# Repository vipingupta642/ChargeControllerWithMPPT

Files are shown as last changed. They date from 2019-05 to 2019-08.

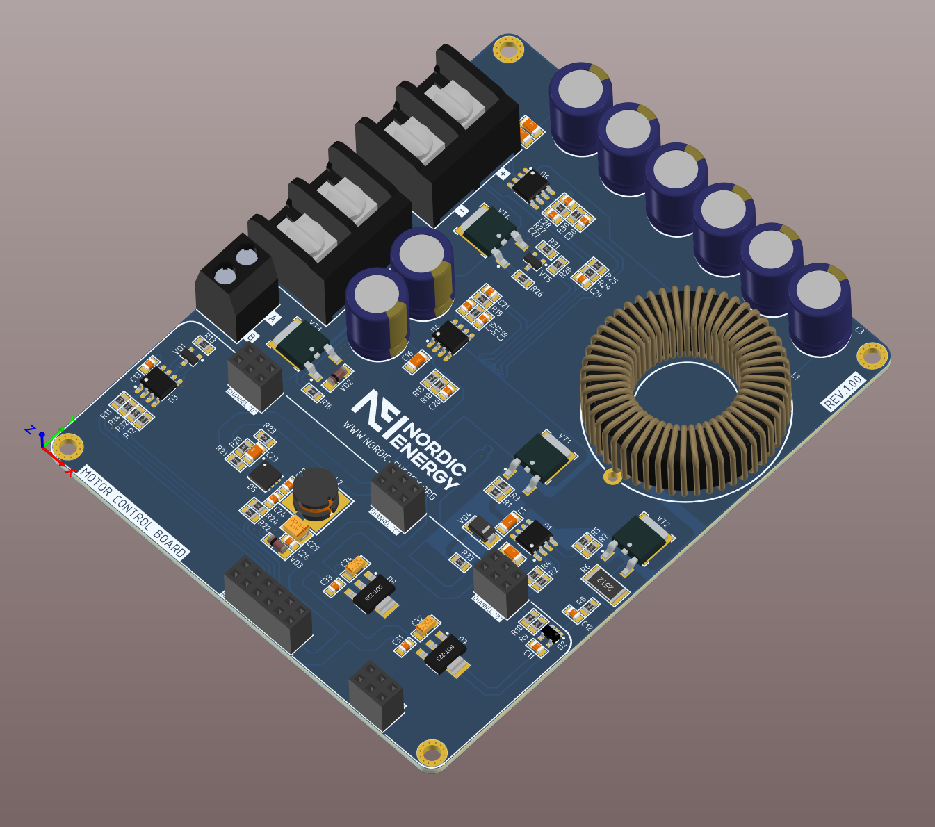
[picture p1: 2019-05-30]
Hardware/Mechanical/3D view. Part 1.PNG

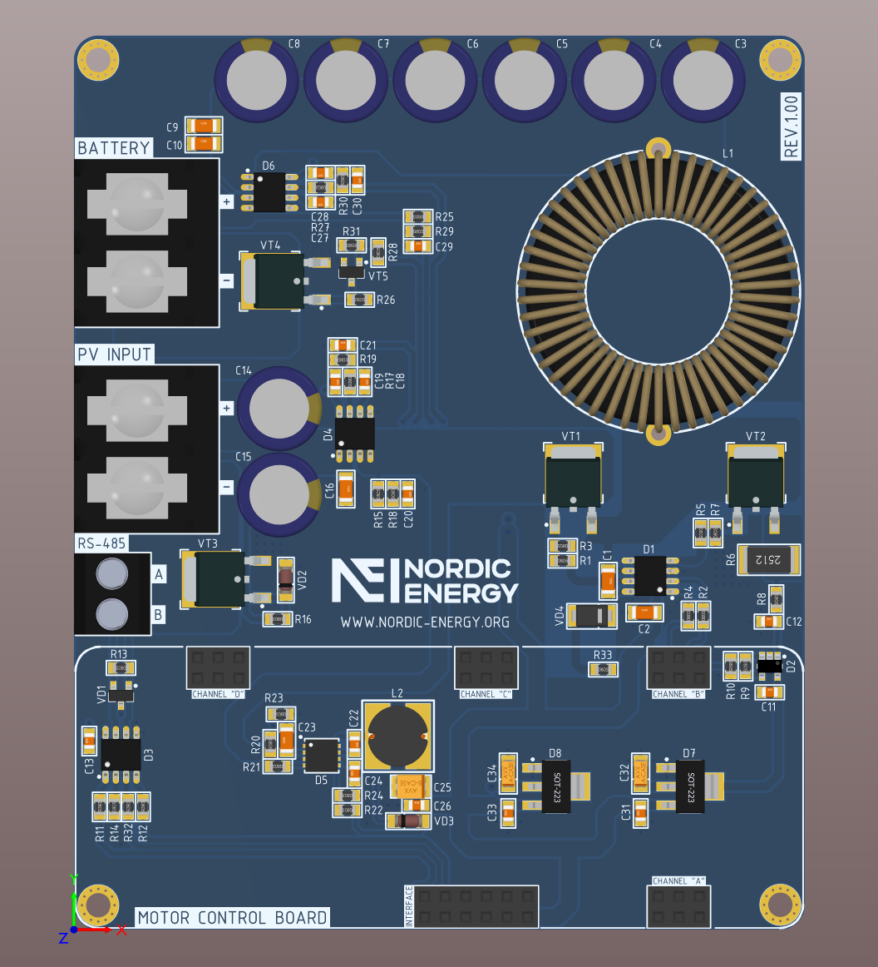
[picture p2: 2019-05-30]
Hardware/Mechanical/3D view. Part 2.PNG

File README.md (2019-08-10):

# МРРТ контроллер заряда батареи

Контроллер заряда создан на базе модуля [*MotorControlBoard*](https://github.com/Nordic-Energy/MotorControlBoard) и управляется с помощью специализированного микроконтроллера STM32F334C8T6 с высокоразрядным ШИМ-контроллером (HRPWM) на борту. Применение данного устройства возможно, как в роли отладочного комплекса для изучения алгоритмов поиска точки максимальной мощности (ТММ), так в качестве законченного устройства для работы в автономной солнечной электростанции мощностью до 500 Вт.

Фото МРРТ

При разработке контроллера заряда основной упор делается на создание надежной аппаратной части с применением лучших компонентов и на реализацию максимальной эффективных алгоритмов поиска ТММ. В контроллере отсутствую электролитические конденсаторы, вместо них примененые твердотельные полимерные конденсаторы с повышенным сроком службы, что позволит обеспечить устройству гарантированный ресурс работы 10 лет. Это приведет к увеличению надежности автономных мини-электростанций и снижению затрат на обслуживание оборудования.

# Технические характеристики

* Входное напряжение: *15...60В*
* Выходное напряжение: *12/24В*
* Выходной зарядный ток: *20А*
* Стабилизация тока: *±1,5%*
* Стабилизация напряжения: *±2%*
* Рабочая частота: *100кГц*
* КПД, не менее: *94%*
* Алгоритмы МРРТ: *да*
* Интерфейсы: *USB, RS485*
* Габаритные размеры: *110х90х20мм*
* Температура эксплуатации: *-20...+65<sup>o</sup>C*

# Структура проекта

* Firmware
    * Documents
    * ChargeControllerWithMPPT

>

* Hardware
    * Documents
    * Manufacture
    * AltiumProject
    * Mechanical

# Печатная плата

Контроллер заряда состоит из двух плат: [*MotorControlBoard*](https://github.com/Nordic-Energy/MotorControlBoard) и основная силовая  двухслойная плата, которая изготавливается на стеклотекстолите FR-4 толщиной не менее 1 мм (рекомендовано 1,6 мм) и имеет размеры 110х90 мм.

Печатная плата МРРТ контроллера

# Используемые инструменты

* [Altium Designer](https://www.altium.com/altium-designer/ "Официальный сайт CAD")
* [Visual Studio Code](https://code.visualstudio.com/ "Официальный сайт IDE")
* [GNU Arm Embedded Toolchain](https://github.com/gnu-mcu-eclipse/arm-none-eabi-gcc/releases/tag/v8.2.1-1.4 "Официальный сайт плагина")
* [JLink](https://www.segger.com/downloads/jlink/#J-LinkSoftwareAndDocumentationPack "Официальный сайт")

# Лицензирование

Все исходные материалы для проекта распространяются по лицензии [MIT](./LICENSE "Описание лицензии"). Вы можете использовать проект в любом виде, в том числе и для коммерческой деятельности, но стоит помнить, что автор проекта не дает никаких гарантий на работоспособность устройства или частей проекта, а так же не несет никакой ответственности по искам или за нанесенный ущерб.

# Контакты

* E-mail: *ilya@nordic-energy.org*
* Telegram: [*@aiki01*](https://t.me/aiki01 "Чат в телеграмме")

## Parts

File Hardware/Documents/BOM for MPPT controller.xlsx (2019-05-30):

Value | Designator | Manufacturer | Model | Quantity
0.47μF | C1 | Yageo | CC1206KRX7R8BB474 | 1
2.2μF | C2, C9, C10 | Yageo | CC1206KKX7R9BB225 | 3
330μF | C3, C4, C5, C6, C7, C8 | Panasonic | 35SEK330M | 6
0.1μF | C11, C13, C19, C20, C21, C28, C29, C30 | Yageo | CC0805KRX7R8BB104 | 8
1nF | C12, C18, C27 | Yageo | CC0805KRX7R9BB102 | 3
100μF | C14, C15 | Wurth | 860010775014 | 2
1μF | C16, C23 | Samsung | CL31B105KCHSNNE | 2
0.01μF | C22 | Yageo | CC0805KRX7R9BB103 | 1
2.2μF | C24 | Yageo | CC0805KKX7R6BB225 | 1
10μF | C25 | AVX | TAJB106K025RNJ | 1
2.2μF | C26 | Yageo | CC0805KKX7R7BB225 | 1
1μF | C31, C33 | Yageo | CC0805JKX7R7BB105 | 2
100μF | C32, C34 | AVX | TLJA107M006R0800 | 2
 | D1 | ON Semiconductor | NCP5183DR2G | 1
 | D2 | Texas Instruments | LMV321IDBVR | 1
 | D3 | Texas Instruments | SN65HVD3082EDR | 1
 | D4, D6 | Allegro MicroSystems | ACS713ELCTR-30A-T | 2
 | D5 | Texas Instruments | LM5017SD/NOPB | 1
 | D7 | Diodes Incorporated | AZ1117IH-3.3TRG1 | 1
 | D8 | Diodes Incorporated | AZ1117IH-5.0TRG1 | 1
30μH | L1 | Magnetics | 0077071A7 | 1
220μH | L2 | Bourns | SDR0805-221KL | 1
2R4 | R1, R5, R33 | Yageo | RC0805JR-072R4L | 3
100R | R2, R4, R8, R11, R12, R28, R32 | Yageo | RC0805JR-07100RL | 7
10k | R3, R7, R14, R16, R26, R31 | Yageo | RC0805JR-0710KL | 6
0R004 | R6 | Yageo | PA2512FKF7W0R004E | 1
30k | R9 | Yageo | RC0805FR-0730KL | 1
1k | R10 | Yageo | RC0805FR-071KL | 1
120R | R13 | Yageo | RC0805FR-07120RL | 1
100k | R15 | Yageo | RC0805FR-07100KL | 1
5k6 | R17, R18, R27 | Yageo | RC0805FR-075K6L | 3
10k | R19, R23, R24, R29, R30 | Yageo | RC0805FR-0710KL | 5
91k | R20 | Yageo | RC0805FR-0791KL | 1
499k | R21 | Yageo | RC0805FR-07499KL | 1
88k7 | R22 | Yageo | RC0805FR-0788K7L | 1
82k | R25 | Yageo | RC0805FR-0782KL | 1
 | VD1 | ON Semiconductor | SZNUP2105LT1G | 1
16V | VD2 | Central Semiconductor | CLL5246B TR | 1
 | VD3 | ON Semiconductor | LL4148 | 1
 | VD4 | SMC Diode | SS210ATR | 1
 | VT1, VT2, VT3, VT4 | Infineon | IPD053N08N3GATMA1 | 4
 | VT5 | ON Semiconductor | BC847ALT1G | 1
 | X1 | Connfly | PBD-12 | 1
 | X2, X3, X4, X5 | Connfly | PBD-6 | 4
 | X6 | Molex | 0395430002 | 1
 | X7, X8 | TE Connectivity | 6PCV-02-006 | 2

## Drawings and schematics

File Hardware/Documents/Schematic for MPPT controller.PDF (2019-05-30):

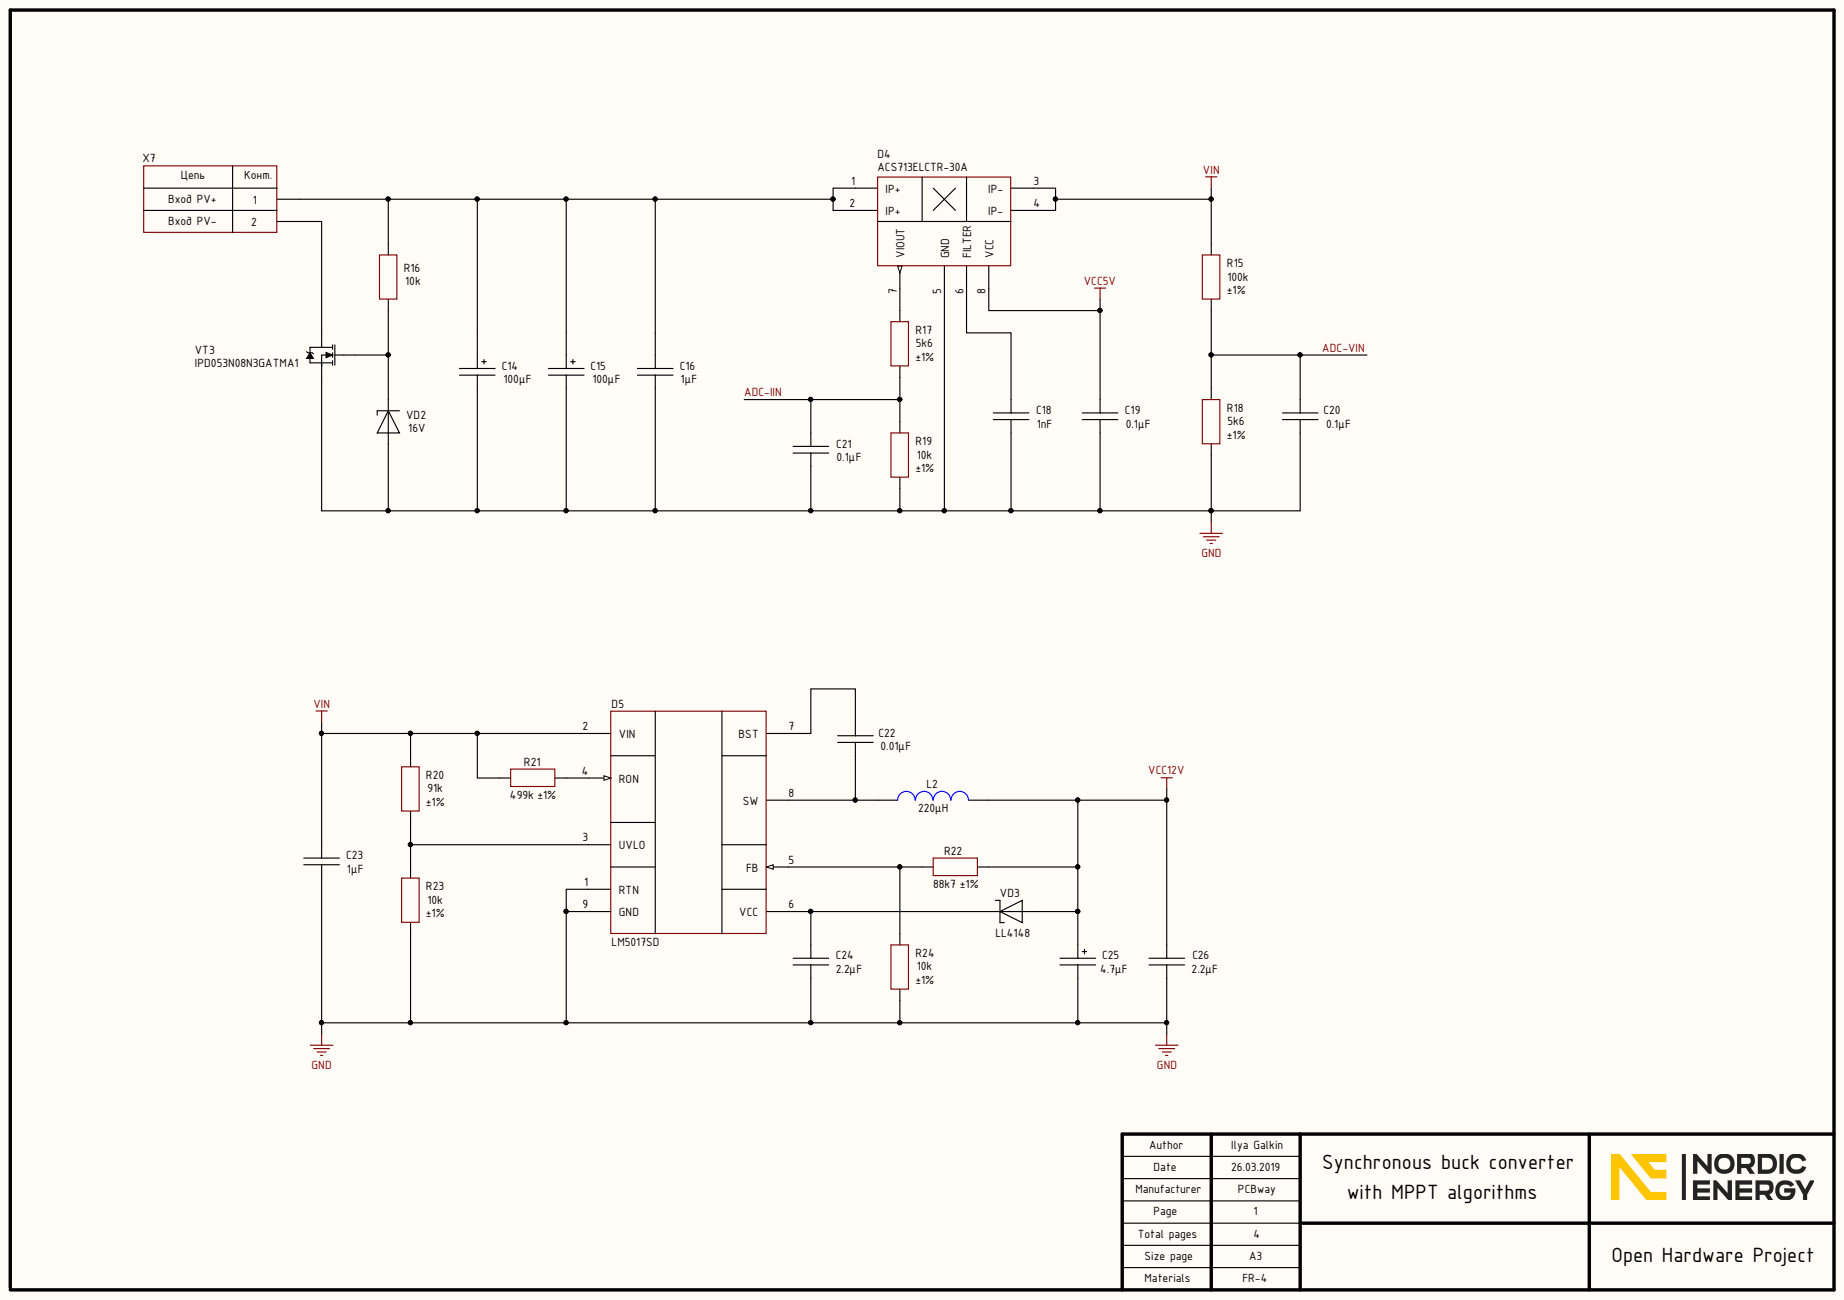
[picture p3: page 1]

Цепь | Конт.

Вход PV+ | 1

Вход PV- | 2

Author | Ilya Galkin | Synchronous buck converter with MPPT algorithms

Date | 26.03.2019

Manufacturer | PCBway

Page | 1

Total pages | 4 | | Open Hardware Project

Size page | A3

Materials | FR-4

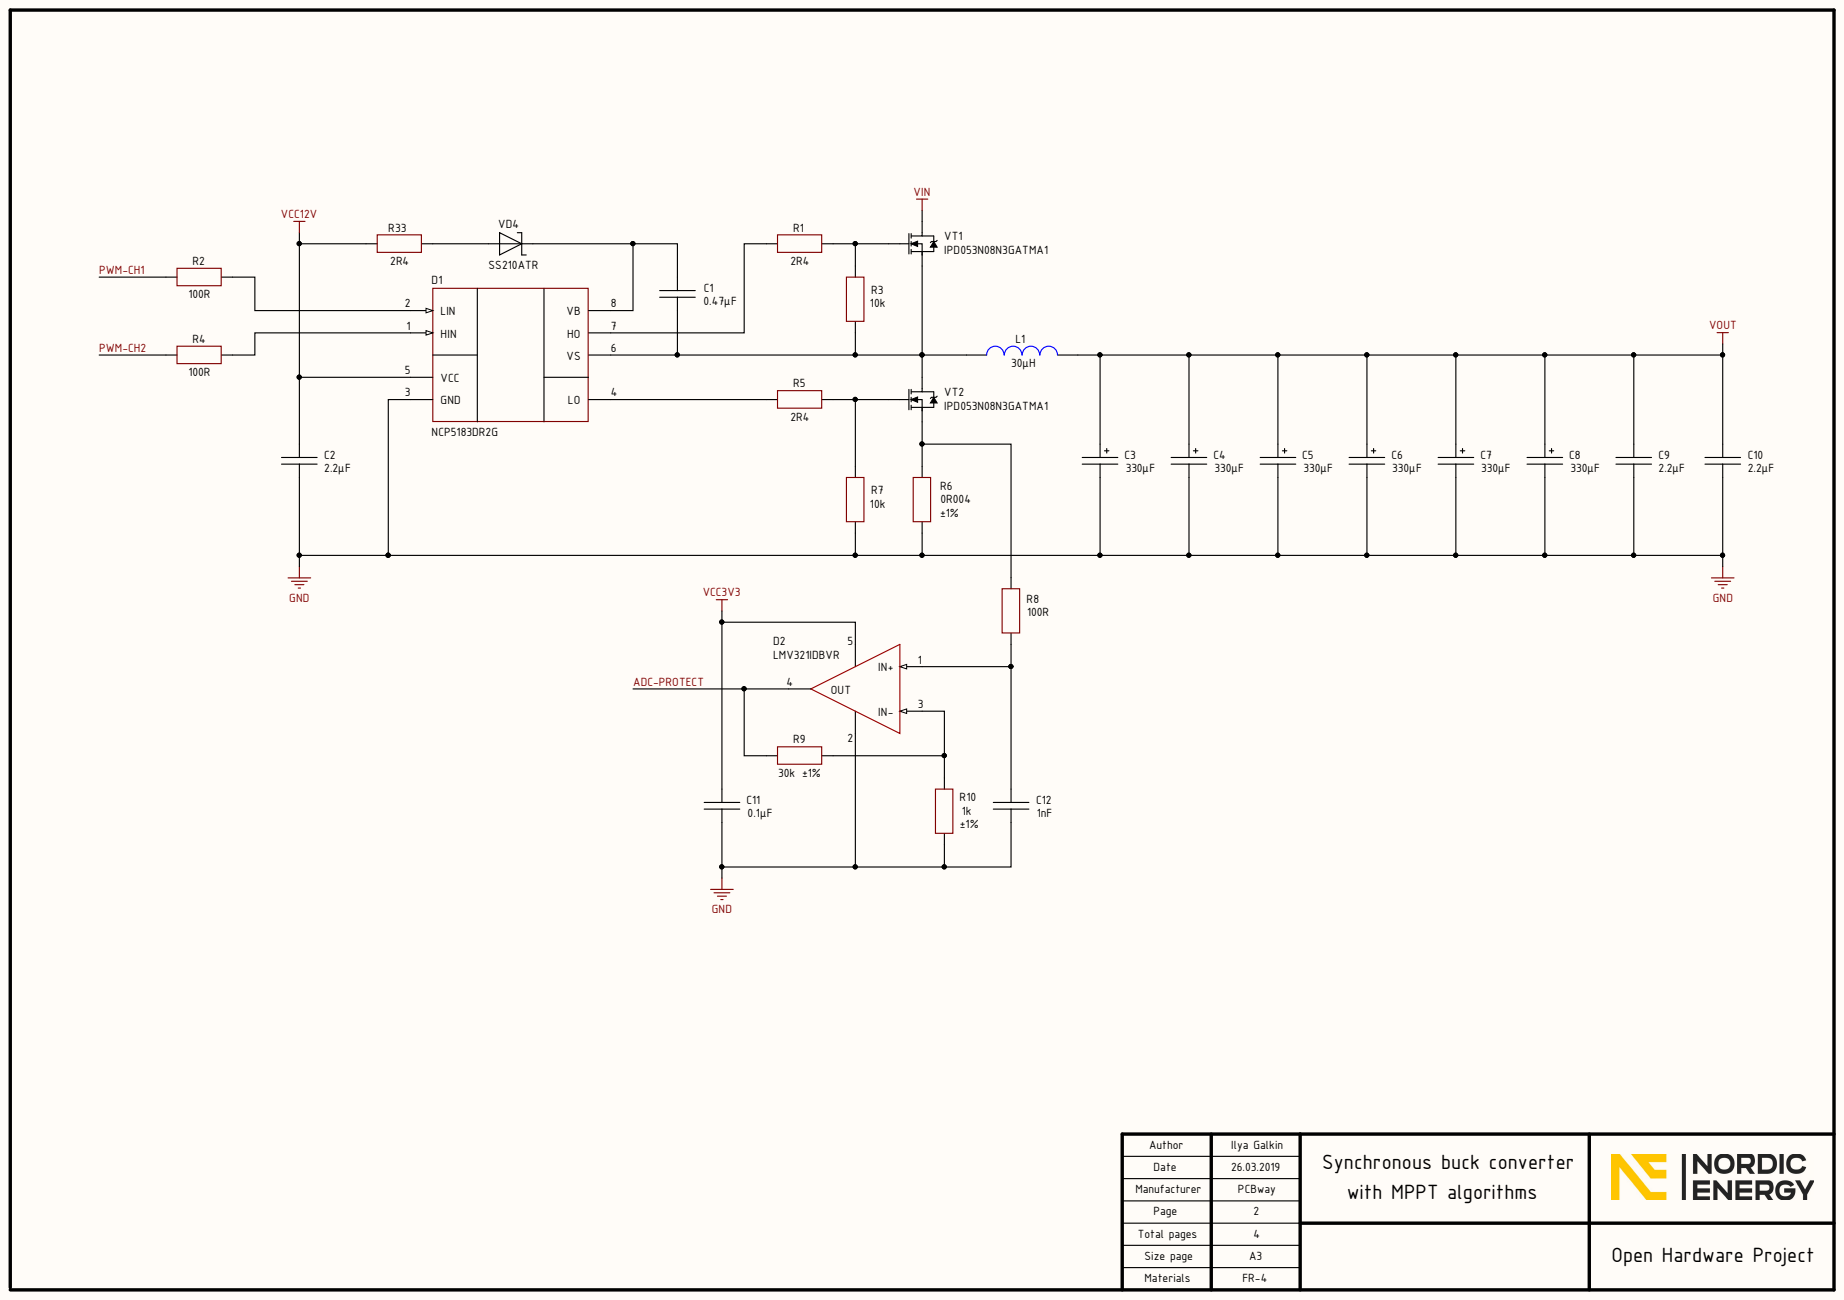
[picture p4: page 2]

5 | VCC G N D

26.03.2019 PCBway 24

Manufacturer Page Total pages

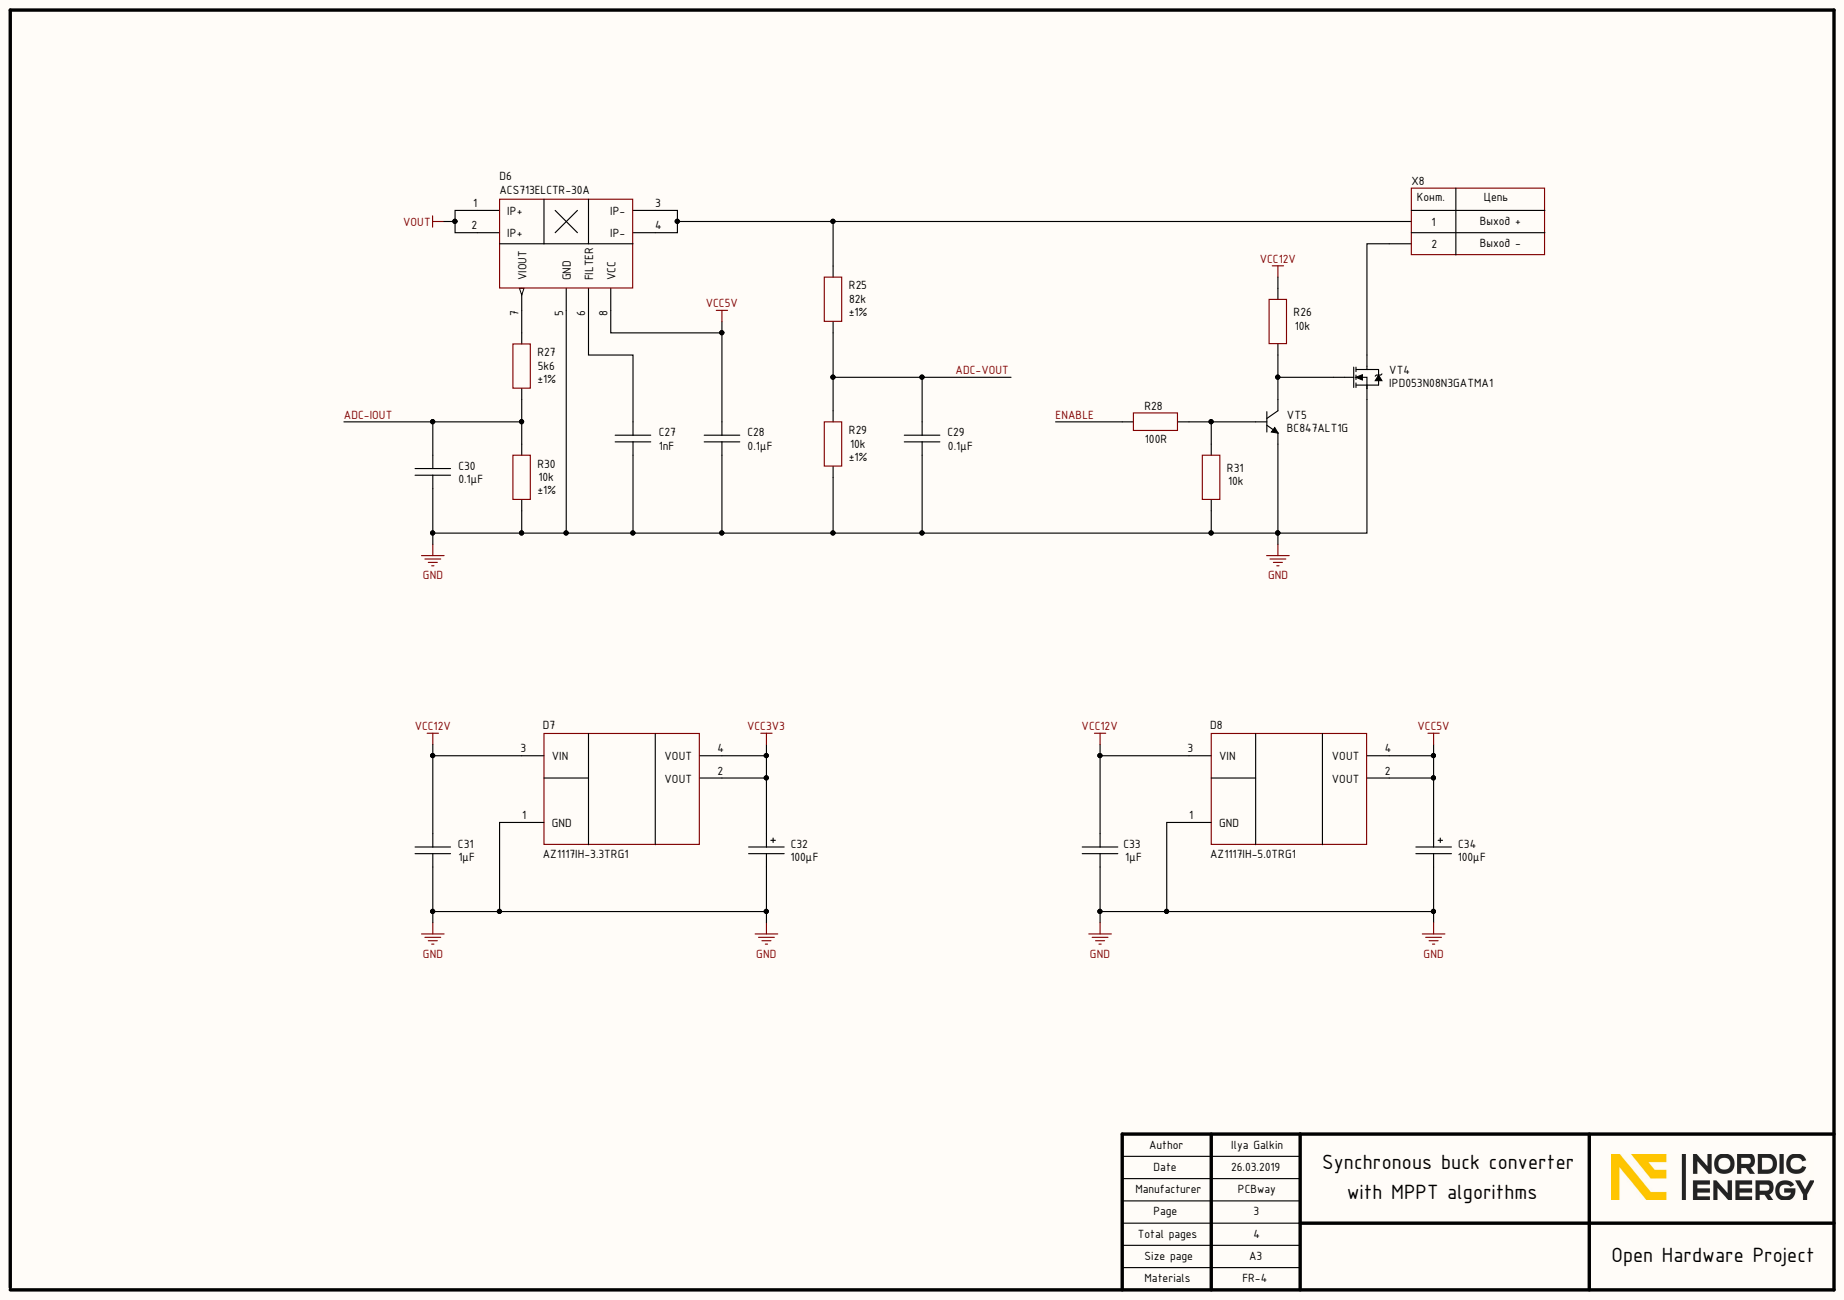
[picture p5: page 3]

Конт. | Цепь

1 | Выход +

2 | Выход -

Author | Ilya Galkin | Synchronous buck converter with MPPT algorithms

Date | 26.03.2019

Manufacturer | PCBway

Page | 3

Total pages | 4

Size page | A3

Materials

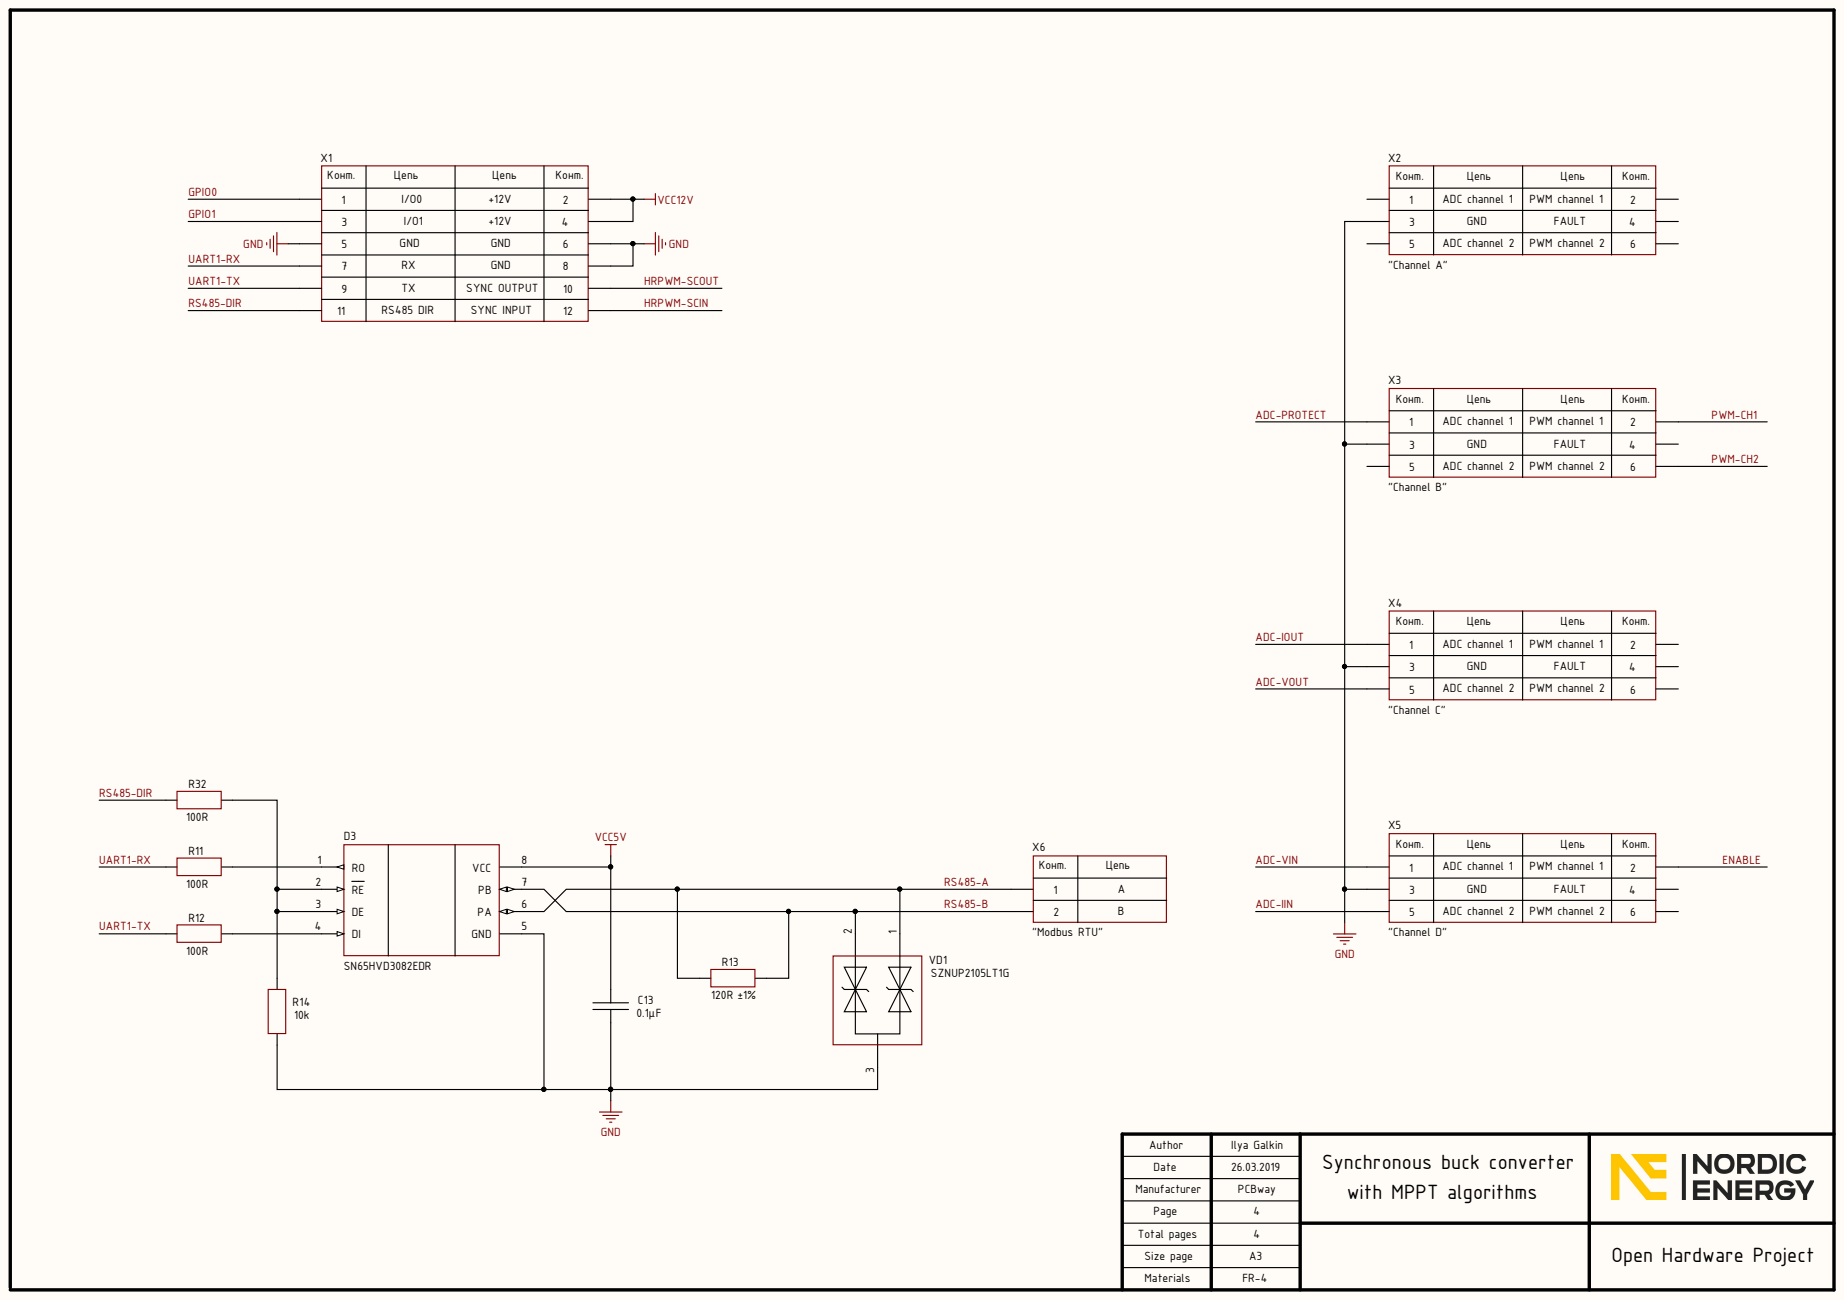
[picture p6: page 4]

9 | T X | SYNC O U T P U T | 10

11 | R S 485 D I R | SYNC I N P U T | 12

Цепь | Конт .

ADC channel 1 | | 24

ADC channel 2 GND | FAULT PWM channel 1 PWM channel 2

Конт . | Цепь | Цепь | Конт .

13 | ADC channel 1 | | 24

26.03.2019 PCBway 44

Manufacturer Page Total pages

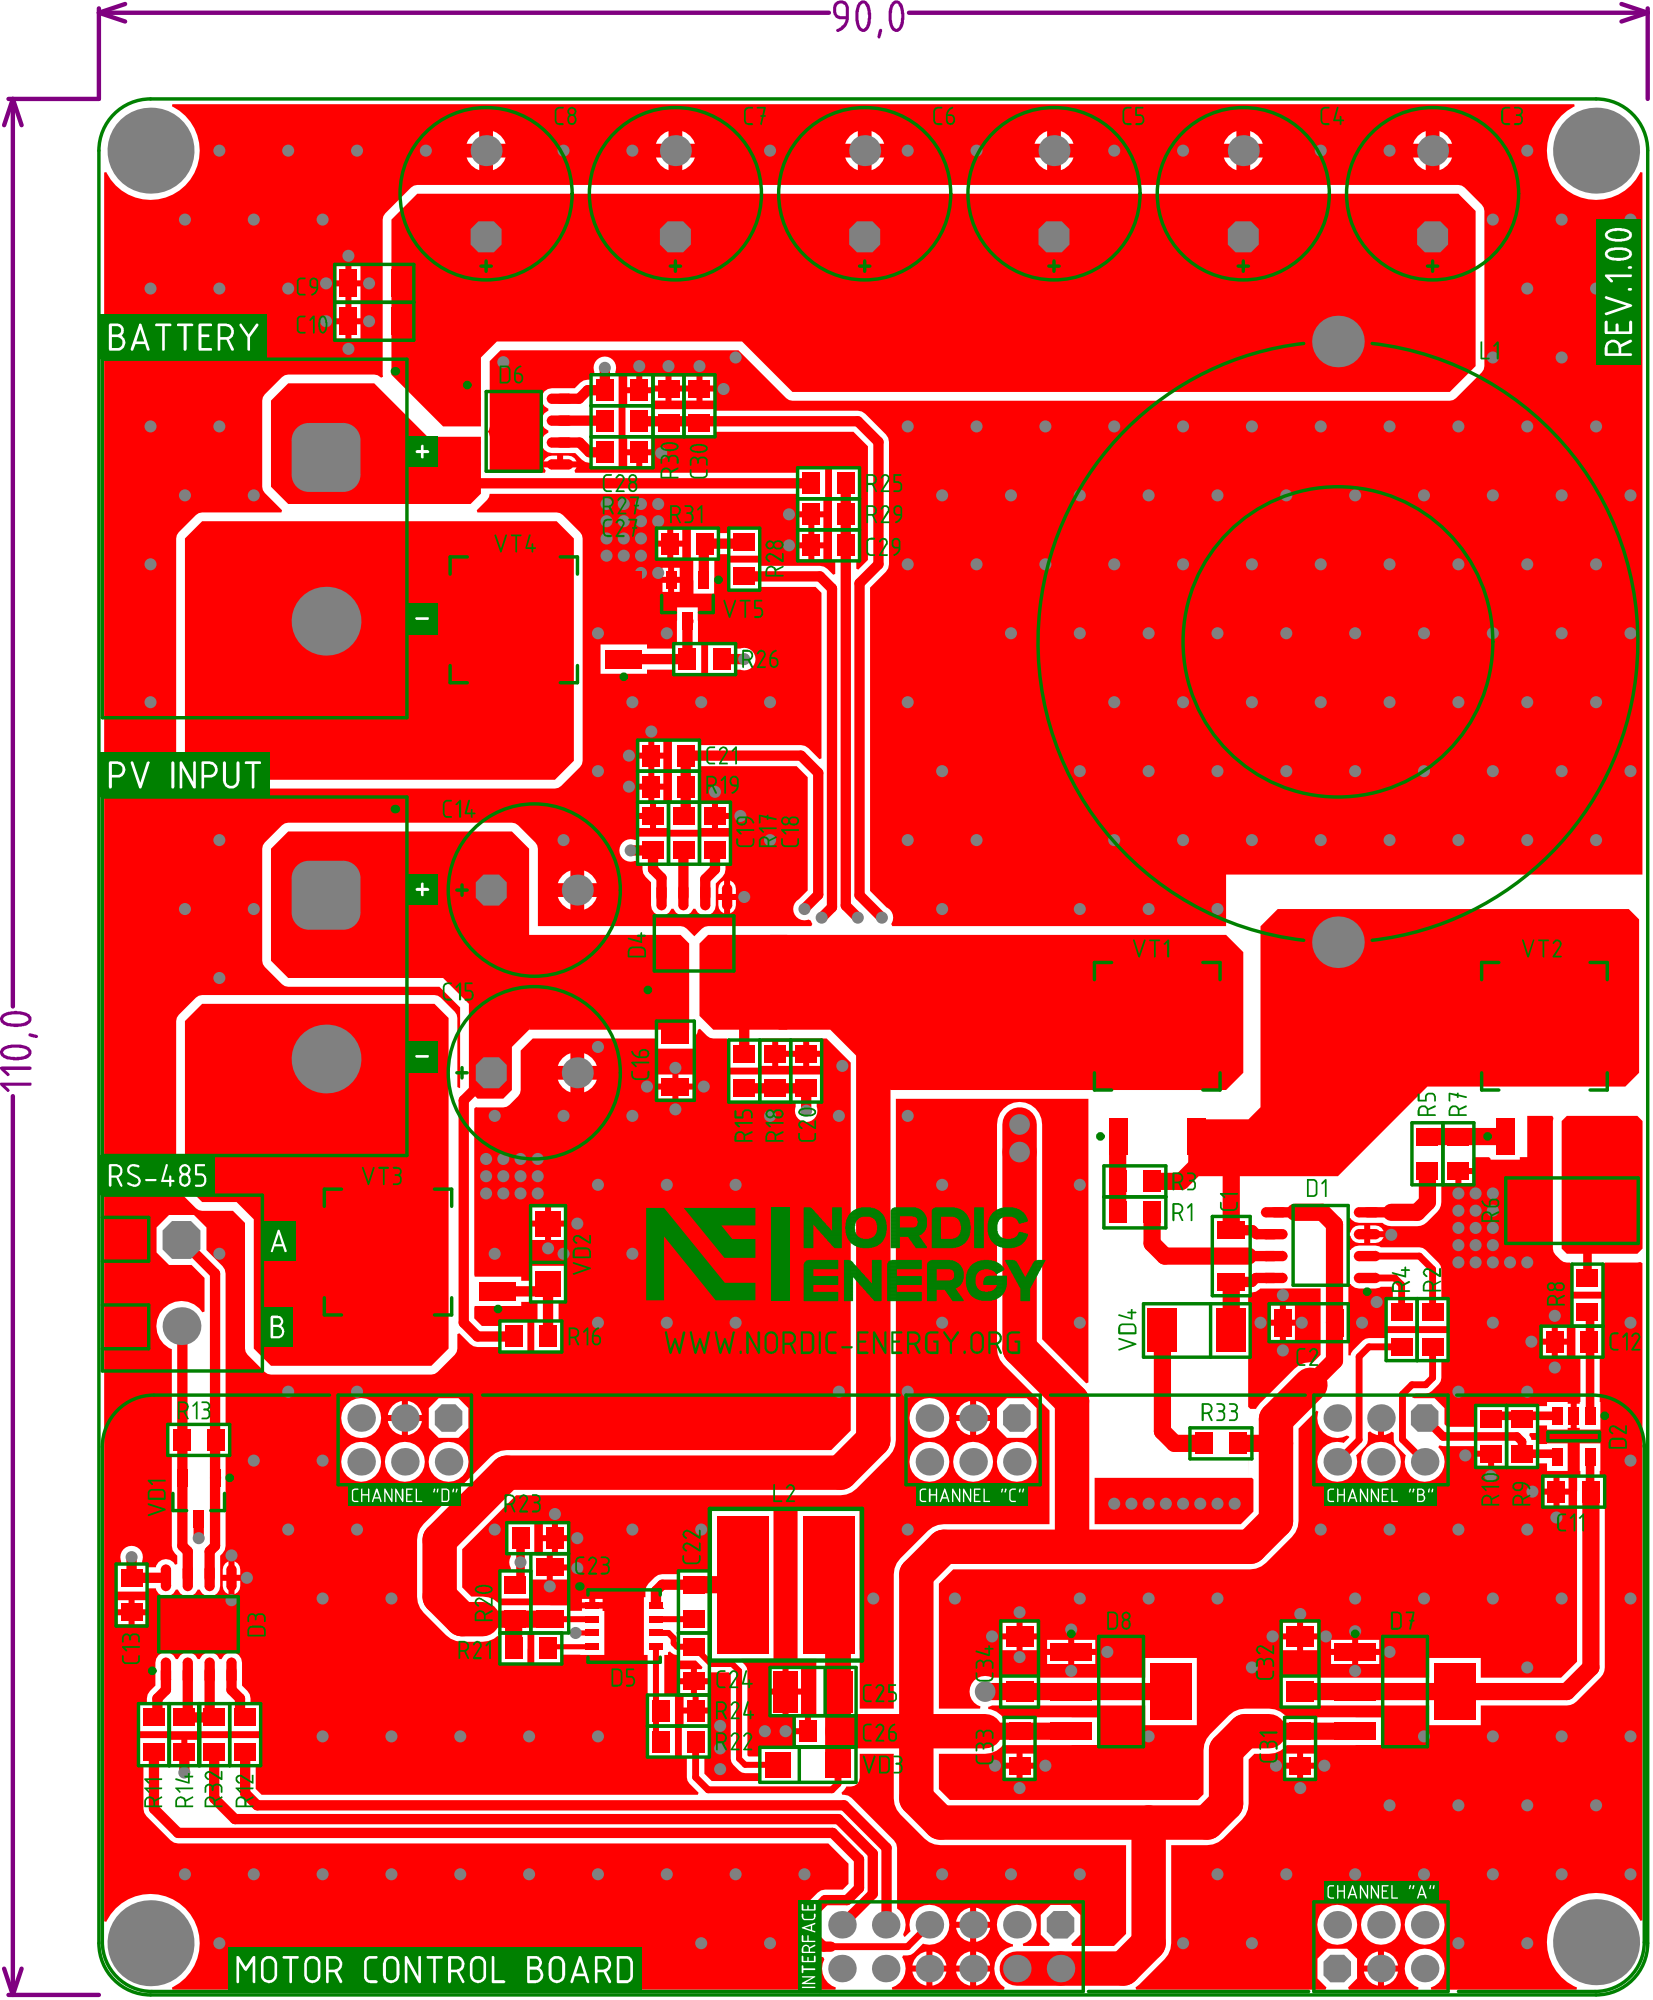
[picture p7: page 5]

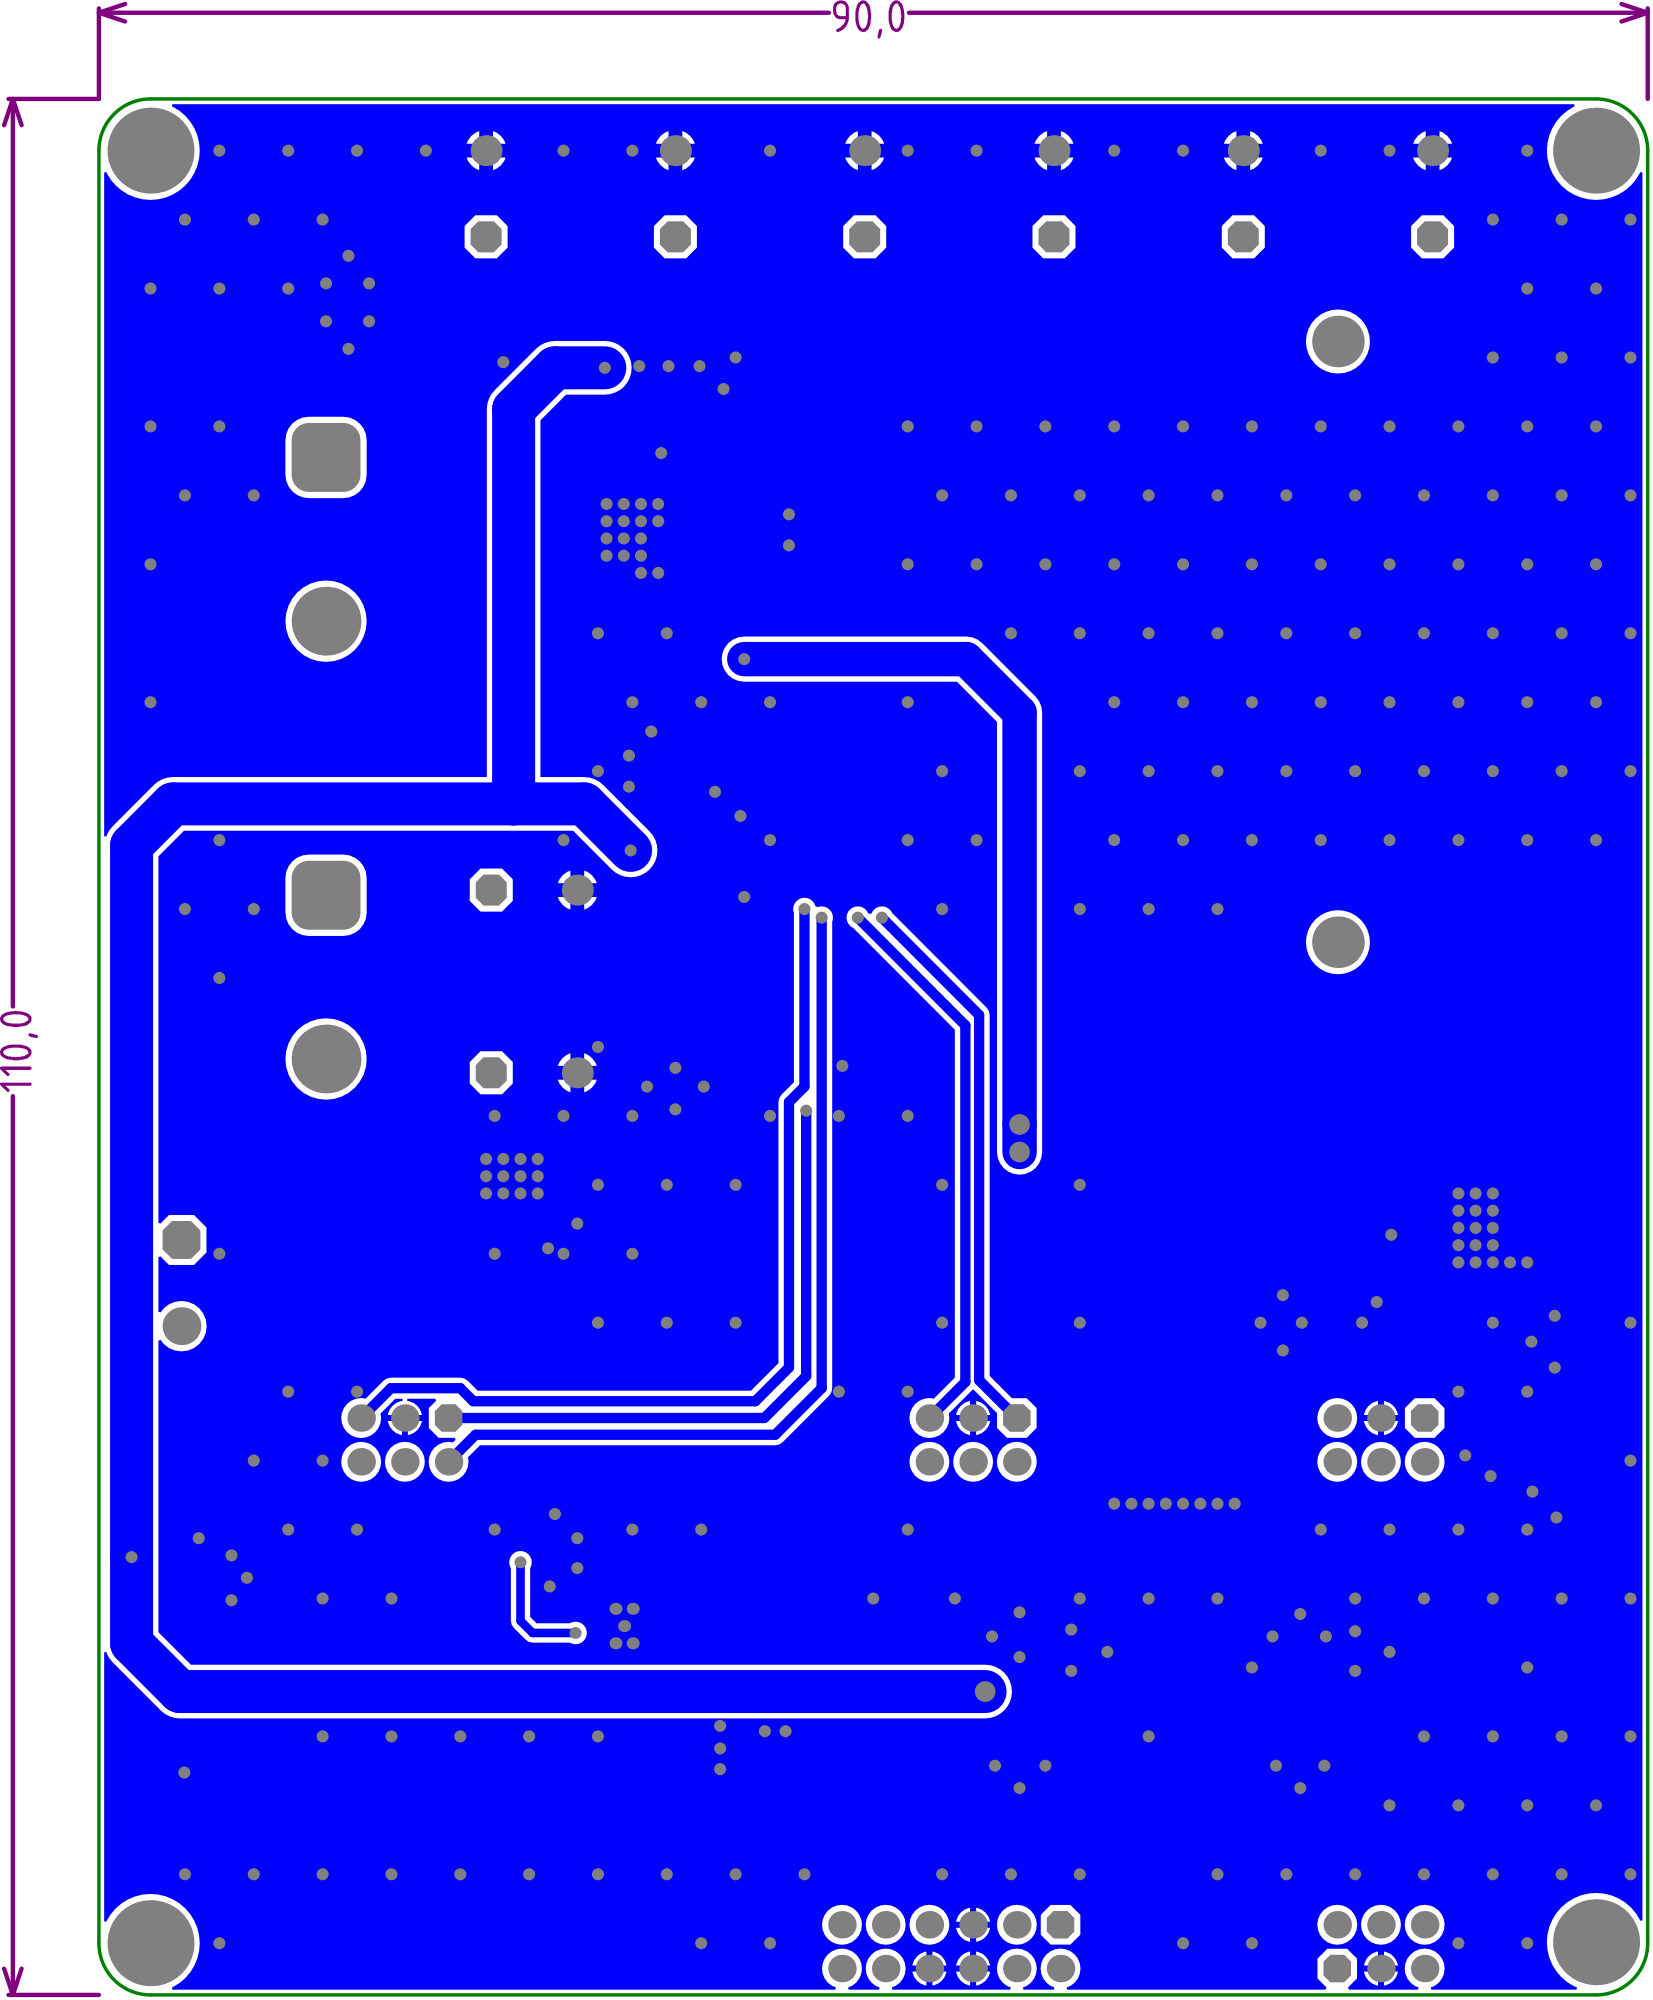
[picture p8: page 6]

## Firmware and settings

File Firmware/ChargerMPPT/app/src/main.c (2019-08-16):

/********************************************************************************
 * project     Charge controller for solar panel with MPPT algorithm            *
 *                                                                              *
 * file        main.c                                                           *
 * author      Ila Galkin (aka Nordic Energy)                                   *
 * date        15.07.2019                                                       *
 * copyright   The MIT License (MIT). Copyright (c) 2019 Ilya Galkin            *
 * brief       Main program body                                                *
 *                                                                              *
 ********************************************************************************/

/********************************************************************************
 * Include 
 ********************************************************************************/

#include "main.h"

/********************************************************************************
 * Main program body
 ********************************************************************************/

int main (void) {

    StopAllConverter();
   
    BasicInitPeripheral();
    StartSystemMonitoring();
    
    StartChargeBattery();  
    SetDutyTimerB (27000);

    ControlOutputConverter (Enable);

    printf ("End initialization MCU\n");

    while(1) {

        ToggleLedOnBoard (Blue);
        Delay (1000);
    }

}

/********************************* END OF FILE **********************************/

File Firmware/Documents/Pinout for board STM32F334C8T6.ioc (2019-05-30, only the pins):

Mcu.UserName=STM32F334C8Tx
PA0.Signal=ADC1_IN1
PA1.Signal=ADC1_IN2
PA10.Signal=HRTIM1_CHB1
PA11.Signal=HRTIM1_CHB2
PA12.Signal=HRTIM1_FLT1
PA13.Signal=SYS_JTMS-SWDIO
PA14.Signal=SYS_JTCK-SWCLK
PA15.Signal=HRTIM1_FLT2
PA2.Signal=ADC1_IN3
PA3.Signal=ADC1_IN4
PA4.Signal=ADC2_IN1
PA5.Signal=ADC2_IN2
PA6.Signal=ADC2_IN3
PA7.Signal=ADC2_IN4
PA8.Signal=HRTIM1_CHA1
PA9.Signal=HRTIM1_CHA2
PB0.Signal=ADC1_IN11
PB1.Signal=HRTIM1_SCOUT
PB10.Signal=HRTIM1_FLT3
PB11.Signal=HRTIM1_FLT4
PB12.Signal=HRTIM1_CHC1
PB13.Signal=HRTIM1_CHC2
PB14.Signal=HRTIM1_CHD1
PB15.Signal=HRTIM1_CHD2
PB2.Signal=HRTIM1_SCIN
PB3.Signal=SYS_JTDO-TRACESWO
PB4.GPIO_Label=PWM-BUZZER
PB4.Signal=S_TIM3_CH1
PB5.GPIO_Label=RS485-DIR
PB5.Signal=GPIO_Output
PB6.Signal=USART1_TX
PB7.Signal=USART1_RX
PB8.Signal=I2C1_SCL
PB9.Signal=I2C1_SDA
PC13.GPIO_Label=BUTTON
PC13.Signal=GPIO_Input

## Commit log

2019-05-30 git init
    [BOM for MPPT controller.xlsx, Buck converter. Page 2.SchDoc, Control board. Page 4.SchDoc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]
2019-07-07 new: Добавил настроенный стартовый проект в VS Code
    Для разработки применил связку VS Code + GCC, сборка проекта
    осуществляется с помощью GNU MCU Eclipse Windows Build Tools.
    Использую отладчик JLink.
2019-07-18 new: Добавил функцию управления светодиодами и кнопкой
    Добавлена функция для управления светодиодами, а так же
    настроено внешнее прерывание (exti) с кнопки для
    управления запуском контроллера
2019-07-18 docs: Добавил даташит и референс мануал для STM32F334
2019-07-30 fix: Добавил исключение папки build для кода
2019-07-30 new: Добавил функцию toggle для светодиодов
2019-07-30 docs: Добавил даташит и референсе мануал для F334
2019-07-30 new: Добавил настройки системы тактирования
    - Настроил тактирование микроконтроллера от внешнего
    кварцевого резонатора с частотой 8 МГц. Частота системной
    шины равна по умолчанию 72 МГц;
    - Настроил задержку для встроенной flash-памяти в
    соответствии с RM для частоты 72 МГц;
    - Установил делитель /10 для тактирования АЦП, т.к.
    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
2019-07-31 fix: Исправил множитель частоты с 6 на 9 для 72 МГц
    В процессе настройки допустил ошибку с множителем, в итоге
    не работал UART. После проверки частоты на MCO увидел
    48 МГЦ вместо ожидаемых 72 МГц. Ошибка была найдена в
    множители частоты PLL, он был 6 вместо 9.
    [SystemAndClock.c]
2019-07-31 new: Добавил библиотеку для отправки и приема данных в UART1
2019-07-31 new: Добавил исключение папки _Previwes для Altium
2019-07-31 new: Добавил базовую настройку HRPWM
    Запустил dc/dc преобразователь. Для управления
    настроил HRPWM канал В на частоту около 100 кГц.
    Установил мертвое время по фронту и спаду 104 нс.
2019-07-31 refactor: Объявил период таймеров HRPWM как переменные, а не дефайны
2019-08-01 new: Добавил реализацию отладки через printf
    Реализовал перенаправление стандартной функции printf
    в UART1 для вывода в терминал. Для вывода отладочной
    информации из фалйа необходимо подключить файл DebugOutput.h
    и выводить данные с помощью printf().
2019-08-01 refactor: Удалил не используемые функции-заглушки
    Удалил функции-заглушки для стандартных операций stdio,
    которые не используются в работе printf, так как
    не использую ничего кроме вывода отладочной информации
    в консоль.
2019-08-01 docs: Исправил список используемых инструментов разработки
2019-08-10 fix: Исправил сброс флагов в прерывание USART
    Выявил и исправил трудноуловимый баг, МК не доходил до
    цикла while, т.к. зависал в прерывание по USART.
    Сброс флага происходил с помощью записи в бит RXNE
    регистра ISR, тогда как для данного МК с раздельными
    буфером приема и передачи необходимо сбрасывать флаг
    записью в бит RXFRQ в регистре RQR.
    [USART.c]
2019-08-10 new: Добавил аппаратную реализацию задержки delay
    Функция delay реализована на системном таймере (SysTick) и не
    вызывает простоя в работе ядра, а так же не вносит практически
    никаких задержек в реал-тайм. Функция в качестве аргумента
    принимает значение задержки в милисекундах.
2019-08-10 docs: Добавил исключение настроек дебага
2019-08-10 new: Настроил и запустил АЦП по триггеру HRPWM
    Выполнил настройку АЦП, пока 1 регулярный канал, в дальнейшем
    необходимо настроить 4 инжекторных канала для ADC2 + передача
    DMA. Триггер для запуска АЦП по компаратору №2 от таймера В
    в HRTIM1. Частота семплирования 100 кГц. Вывел в терминал
    значение выходного напряжения.
    Исправил комментарий в DebugOutput.c
    [HighResolutionPWM.c, LedAndButton.c, VoltageAndCurrentAdc.c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]
2019-08-12 new: Настроил АЦП в инжекторном режиме на 4 канала
    Теперь контроллер умеет измерять входное напряжение и ток,
    а так же выходное напряжение и ток, что позволяет реализовать
    алгоритм заряда АКБ и МРРТ.
2019-08-14 new: Глобально переработал архитектуру и структуру проекта
    - Изменил структуру папко и расположения файлов с кодом в них.
    Теперь в папке cmsis находятся стандартные файлы драйверов. В
    папке drivers находятся высокоуровневые драйвера. В папке
    app собственно основная логика приложения. Файлы линковки и
    стартап перенесены в свои папки;
    - Выделил в отдельную часть проекта вывод отладочной ин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
2019-08-16 new: Добавил в мейкфайл флаг для вывода float в printf
    При попытке вывести переменную типа float с помощью
    стандартной функции printf выводило пустоту на
    месте числа. Оказалось, что для вывода переменных
    типа %f нужно добавить в makefile флаг компилятору:
    -u_printf_float. Я добавил флаг и функция printf
    начала корректно выводить переменные float.
2019-08-16 new: Настроил вывод данных с АЦП в терминал
    Преобразовал данные в читаемый вид в Вольты и Амперы,
    теперь в терминал выводятся данные о входном и выходном
    токах, а так же о входном и выходном напряжениях.
2019-08-16 new: Добавил фильтрацию данных с АЦП и преобразовал их
    - Перевел все расчеты во float и привел все результаты
    измерений с АЦП в привычные единицы (вольты и амперы).
    - Добавил фильтрацию данных простым вычислением среднего
    арифметического значения за 10 измерений. Это позволило
    измерять напряжение с точностью до 2-го знака, а ток до 1-го.
    - Добавил функцию, которая в самом начале инициализ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
